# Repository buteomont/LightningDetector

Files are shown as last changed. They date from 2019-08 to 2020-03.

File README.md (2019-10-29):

# LightningDetector  
## An electronic optical lightning detector and strike logger

This device optically detects nearby lightning strikes, records them, and (optionally) energizes a relay for a specified period after each strike.  This version is based on the ESP8266 WEMOS board, but can be adapted to other processors as well.  Firmware development was done in the Arduino IDE.

### Hardware
The hardware is dead simple, as most of the heavy lifting is done by the ESP board and its libraries. An inexpensive solar cell is used as an optical sensor. This solar cell and the WEMOS board is really all that is needed to make a functioning lightning logger.  The output from the solar cell is fed to the processor's ADC (analog-to-digital converter) directly. An optional control circuit (not shown) can be added to energize a relay for a predetermined amount of time whenever lightning is detected.  The circuit can be battery powered, with the strike detector doing double-duty to charge the battery (but don't expect the battery to stay charged unless you are using a _huge_ solar cell).  Thanks to the small size of the WEMOS circuit board, the entire detector will fit inside the head of one of those solar path lights that can be purchased from Dollar Tree, with the solar cell already mounted!  I have included a 3D printer STL file that makes a mount to hold the Wemos board and sounder inside one of these lights. 

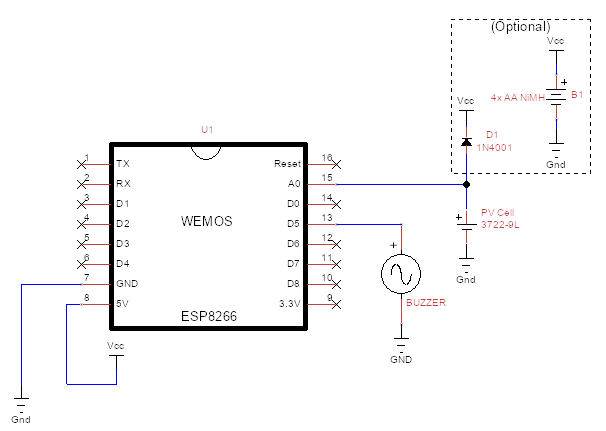
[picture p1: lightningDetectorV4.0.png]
Circuit Schematic Schematic


### Firmware
The program to drive the lightning detector allows you to view or download the strike log and adjust the operating parameters. It operates as a basic web server, while concurrently watching for any lightning in the area.  When a lightning strike is detected, it will record the time and the intensity in the strike log.   

When powered up for the first time, the 8266 will go into "AP mode", since it doesn't know about any wifi routers in the area.  In AP mode, the ESP8266 *is* the router, with an SSID of "**_lightning!_**".  You will need to connect to that "router" and browse to _http://lightning.local_ to configure it.  Enter your household wifi SSID and password and press the _Update_ button.  You can also change the mDNS domain name and sensitivity setting.   

If you enter the SSID or password incorrectly, the lightning detector will never connect to your LAN, and also will not enter AP mode so you can change it!  The way around this is to press the _reset_ button on the WEMOS board and watch for the LED to illuminate.  When it does, press the _reset_ button again.  This will wipe the configuration and cause it to enter AP mode again.  

To reduce false detections, the program will ensure that the length of the strike is above a certain amplitude and within a specific duration window, no shorter and no longer. That window is from 1 to 200 milliseconds and may need to change if too many false positives are recorded or strikes are missed.  The amplitude threshold (sensitivity) of the detector is adjustable on the _/config_ page of the detector's web server.  I've found it's easy to find the right value by putting the detector into place and setting the sensitivity to 1 (maximum sensitivity), and letting it run for a while.  Then noting the values in the strike log makes it easy to adjust the sensitivity to just above the highest value.   

The optional sounder (buzzer) can be enabled or disabled.  The pitch of the beep it produces can be adjusted within a limited range, but be aware that most sounders have a narrow frequency band where they are resonant, so adjusting the pitch will likely affect the volume as well. 

There is no security implemented at this time, so anyone with access to the _/configure_ page can make changes. This will be problematic if you decide to make the logger world-accessible. I purposely did not include a link to the _/configure_ page from the main status page for this reason.  I have plans to add tighter security for this.

The firmware is fully OTA updatable. I would like to see any changes or improvements you come up with!

### Interface
There are several web endpoints that can be accessed when the detector is running and connected to the LAN:
* / or /index.html - The main status page
* /configure - The configuration page for WiFi, LAN, sensitivity, and other changes
* /text - The status and log information in plain text form
* /json - The status and log information in standard machine-readable JSON form

### Problems
* Every WEMOS board I have seen has a stability problem with the ADC while using the WiFi radio.  Turning off the radio seems to give a much more stable reading from the solar cell, but this is not feasible because it must read the solar cell value continuously looking for a strike and it takes several seconds to reconnect the WiFi after being turned back on.  This is a known problem and I have yet to find a solution outside of using an external ADC.
* The detector logs false lightning strikes sometimes right at dawn and right at dusk.  I am not sure what is causing this but I suspect it is related to the stability issue above.  I can prevent a lot of them by reducing the sensitivity but that is not an optimal solution. 

### Planned Enhancements
In addition to fixing the above problems, some of the things I'd like to add when I get the time are
* Security features to require a userid and password when modifying the settings
* The ability to push the strike event to an external service (such as MQTT), email, or SMS account
* More flexibility in configuring the internal parameters
* The ability to remove individual unwanted or error events from the strike log
* Automatically remove strike events from the log that are older than 30 days
* Store the strike log in EEPROM to make it non-volatile

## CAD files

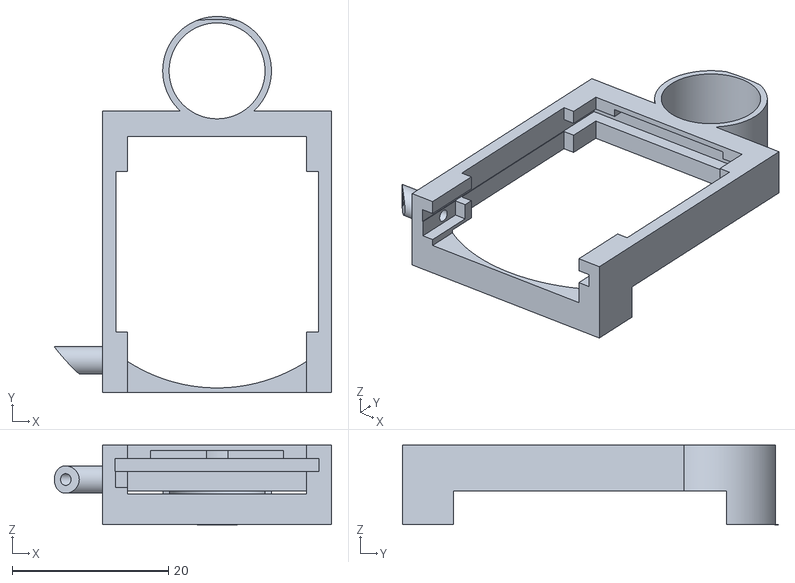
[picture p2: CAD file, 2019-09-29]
case/wemos-holder.stl
35.5 x 48.1 x 10.2

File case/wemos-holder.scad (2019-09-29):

shrinkPCT=3; //%, 1 PLA, 2 PETG, 3 ABS
fudge=.02;  //mm
shrinkFactor=1+shrinkPCT/100;
nozzleDiameter=.4;

$fn=200;

railDepth=1.5; //this is the depth of the slots that the board slides into
metalCapHeight=3.1; //the thickness of the metal cap plus the 8266 board on which it sits

boardWidth=25.9;    //width of the Wemos board
boardLength=34.3;   //length of the Wemos board
boardThickness=1.7; //thickness of the board itself, with a little extra for the groove
boardWallThickness=boardThickness; //the wall thickness at the back of the board groove
boardConnectorEndThickness=4.3;   //the thickness of the board plus the USB connector
antennaWidth=17;    //long dimension of the little PC antenna board
antennaDepth=7;     //short dimension of antenna board
antennaThickness=1; //thickness of antenna board
switchLength=6.5;   //Length of the reset switch, including the gap to the board edge
switchDepth=4.5;    //short dimension of the reset switch
switchHeight=2;     //thickness of the reset switch body
switchButtonOffset=4; //button center from front edge of card
switchButtonDiameter=1.5; //diameter of the reset button access hole
sounderDiameter=11.9;   //diameter of the sounder module
sounderHeight=8.52;    //height of the sounder module
sounderWallThickness=1; //thickness of the wall that holds the sounder in place

baseOuterDiameter=52.2; //the largest diameter of the path light base
baseThickness=1.3;      //the thickness of the plastic base plastic
baseInnerDiameter=40.8; //the diameter of the round embossment in the center of the path light base
baseInnerHeight=4.2;    //the height of the embossment above the base
baseOuterRadius=baseOuterDiameter/2; //sometimes need the radius instead of the diameter

//define a cube that will encompass the entire board. We will remove material from this cube to make the holder
boardCubeHeight=baseInnerHeight+boardConnectorEndThickness+boardThickness;
boardCubeWidth=boardWidth+boardWallThickness*2;
boardCubeLength=boardLength+boardWallThickness; //only need the extra length on the back side, front side flush

//this design works best if it is as close to the edge of the path light wall as possible.  This offset
//is how far the board cube can be moved without going over the edge of the base
boardCubeOffset=(baseOuterRadius+boardCubeLength/2)-(baseOuterRadius+sqrt(pow(baseOuterRadius,2)-pow(boardCubeWidth/2,2))); //this puts the corners of the board right at the edge of the base

boardSpaceWidth=boardWidth-railDepth*2; //the width of the remover for the board and its components 
boardSpaceLength=boardLength-railDepth; //the length of the remover for the board and its components
boardSpaceHeight=boardConnectorEndThickness+metalCapHeight; //this is how tall the remover for the wire space needs to be
boardWireSpaceWidth=boardWidth; //this is the width for the remover for the wire space
boardWireSpaceLength=20.5;      //likewise, the length of the remover
boardWireSpaceOffset=6; //from antenna end of the board


module mount()
  {
  difference()
    {
    union()
      {
      //the main cube that holds the board. Almost everything else is removed from this cube
      translate([0,boardCubeOffset,boardCubeHeight/2+baseThickness])
        {
        cube([boardCubeWidth,boardCubeLength,boardCubeHeight],center=true);
        }
        
      //Add the guide for the reset switch
      translate([-(boardWidth/2+9),
                  boardCubeOffset-(boardLength/2-switchLength/2),
                  baseThickness+baseInnerHeight+boardConnectorEndThickness-boardThickness-switchHeight/2])
        {
        rotate([0,90,0])
          cylinder(h=9,d=switchButtonDiameter+2); //hole housing for the reset button
        }
      
      //add the sounder holder
      translate([0,boardCubeOffset+boardLength/2+sounderDiameter/2+fudge,baseThickness+boardCubeHeight/2])
        {
        cylinder(h=boardCubeHeight,d=sounderDiameter+sounderWallThickness*2,center=true); //hole housing for the sounder
        }
      }
    union() //all of this is removed from the main cube
      {
      cylinder(d=baseOuterDiameter,h=baseThickness+fudge*2); //the thin base
      translate([0,0,baseThickness+fudge])
        {
        cylinder(d=baseInnerDiameter*shrinkFactor, h=baseInnerHeight*shrinkFactor); //the thicker center part of the base
        }
      translate([0,boardCubeOffset-boardWallThickness/2,baseThickness+baseInnerHeight+boardConnectorEndThickness-boardThickness/2])
        {
        cube([boardWidth+.2,boardLength+.2,boardThickness],center=true); //the slot for the card edges
        }
      translate([0,boardCubeOffset-boardWallThickness,baseThickness+baseInnerHeight+boardConnectorEndThickness-boardThickness/2])
        {
        cube([boardSpaceWidth,boardSpaceLength,boardSpaceHeight],center=true); //space for the board components
        }
      translate([0,boardCubeOffset,baseThickness+baseInnerHeight+boardConnectorEndThickness-boardThickness/2])
        {
        cube([boardWireSpaceWidth,boardWireSpaceLength,boardSpaceHeight],center=true); //space for the wire connections. This really should be changed to allow the board to be inserted with the wires attached
        }
      translate([0,boardCubeOffset-antennaDepth/2+boardLength/2,baseThickness+baseInnerHeight+boardConnectorEndThickness+antennaThickness/2-fudge])
        {
        cube([antennaWidth,antennaDepth,antennaThickness],center=true); //space for the antenna board
        }
      translate([-(boardWidth/2-switchDepth/2),boardCubeOffset-(boardLength/2-switchLength/2+boardWallThickness/2),baseThickness+baseInnerHeight+boardConnectorEndThickness-boardThickness-switchHeight/2])
        {
        cube([switchDepth+fudge,switchLength+fudge,switchHeight+fudge],center=true); //space for the reset button
        }
      translate([-(boardWidth/2+8),boardCubeOffset-(boardLength/2-switchLength/2),baseThickness+baseInnerHeight+boardConnectorEndThickness-boardThickness-switchHeight/2])
        {
        rotate([0,90,0])
          cylinder(h=8,d=switchButtonDiameter); //hole for the reset button
        }
      translate([-boardCubeWidth/2-fudge,boardCubeLength/2+boardCubeOffset-2.5,baseThickness+fudge])
        {
        cube([boardCubeWidth+fudge*2,5,baseInnerHeight]); //remover for extraneous bits left over
        }
      //add the sounder
      translate([0,boardCubeOffset+boardLength/2+sounderDiameter/2+fudge,baseThickness+boardCubeHeight/2])
        {
        cylinder(h=boardCubeHeight+fudge,d=sounderDiameter*shrinkFactor,center=true); //hole for the sounder
        }

      }
    fit();
    }
    

  }

//Create a remover ring around the whole thing to make it all fit inside the cap. This is mostly for trimming the reset button guide tube and the sounder holder
module fit()
  {
  difference()
    {
    translate([0,0,baseThickness*shrinkFactor-fudge])
      {
      cylinder(d=baseOuterDiameter+10, h=boardCubeHeight+fudge*2); 
      }
    translate([0,0,baseThickness-fudge])
      {
      cylinder(d=baseOuterDiameter, h=boardCubeHeight+fudge*2); 
      }
    }
  }
  

mount();

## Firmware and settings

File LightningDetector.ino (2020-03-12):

/*
 * LightningDetector.c
 *
 *  Created on: May 9, 2014
 *  Updated on: July 20, 2019
 *      Author: David E. Powell
 *
 *  --------Hardware and Software Enhancements----------
 *  - Move strike log to EEPROM
 *
 */

#include <ArduinoMqttClient.h>
#include <ArduinoOTA.h>
#include <ESP8266WiFi.h>
#include <ESP8266WebServer.h>
#include <ESP8266mDNS.h>
#include "Arduino.h"
#include <pgmspace.h>
#include <ctype.h>
#include <ESP_EEPROM.h>
#include <stdio.h>
#include <Esp.h>
#include <TimeLib.h>
#include "LightningDetector.h"
#include "configpage.h"

#ifndef AP_SSID
  #define AP_SSID "lightning!"
  #define AP_PASS ""
  #define MY_MDNS "lightning" 
  #endif

const char *htmlCr="<br>";
const char *textCr="\n\r";

int lastReading = 0;
int thisReading = 0;
int errval=128; //half way
int resetCounter=0; //keeps the LED lit long enough to see it when a strike happens
int resetDelay=100;  //this is how many milliseconds (approx) the LED stays lit after lightning is seen
unsigned long strikes[MAX_STRIKES];       //strike time log
unsigned int strikeIntensity[MAX_STRIKES];//strike brightness log
int strikeCount=0;  //number of strikes in the log
boolean done=false;
int strikeStage=0;   //to keep track of which part of the strike we are working
long strikeWaitTime; //to keep from having to use delay()
int intensity;       //temporary storage to record the intensity of the strike for the log
boolean configured=false;  //don't look for lightning until we are set up
time_t tod=0;         //time of day
unsigned long ledTime=millis(); //target time to turn off the LED
unsigned long mqttWait=millis(); //used to slow down MQTT connect retries
unsigned long looptime=0;

//IPAddress timeServer(132,163,96,2);  //time.nist.gov
IPAddress timeServer;

ESP8266WebServer server(80);
WiFiUDP Udp; //for getting time from NIST
unsigned int localPort = 8888;  // local port to listen for UDP packets for time query

typedef struct 
  {
  boolean valid=false; //***** This must remain the first item in this structure! *******
  char ssid[SSID_SIZE] = AP_SSID;
  char password[PASSWORD_SIZE] = AP_PASS;
  int statIP[4]={0,0,0,0};
  int statGW[4]={0,0,0,0};
  char myMDNS[MDNS_SIZE]=MY_MDNS;
  int tzOffset=-5;
  int sensitivity=10;  //successive readings have to be at least this much larger than the last reading to register as a strike
  boolean useStatic=false;
  boolean beepOnStrike=true;
  int beepPitch=SOUNDER_PITCH;
  boolean useMqtt=false;
  char mqttBrokerAddress[ADDRESS_SIZE]=AIO_SERVER;
  int mqttBrokerPort=AIO_SERVERPORT;
  char mqttUsername[USERNAME_SIZE]=AIO_USERNAME;
  char mqttPassword[PASSWORD_SIZE]=AIO_KEY;
  char mqttTopic[MQTT_TOPIC_SIZE]=MQTT_TOPIC;
  int dnsServer[4]={0,0,0,0};
  } conf;

conf settings; //all settings in one struct makes it easier to store in EEPROM

// Set up the MQTT client class by passing in the WiFi client and MQTT server and login details.
WiFiClient client;
MqttClient mqttClient(client);

void setup()
  {
  //Set up the serial communications
  Serial.begin(115200); 
  Serial.setTimeout(10000);
  Serial.println();
  delay(500);
  Serial.println("Starting up...");

  //initialze the outputs
  pinMode(LIGHTNING_LED_PIN, OUTPUT);  //we'll use the led to indicate detection
  digitalWrite(LIGHTNING_LED_PIN,HIGH); //High is off on the dorkboard
  pinMode(BLUE_LED_PIN, OUTPUT);  //we'll use this led to indicate when we're looking for server connections
  digitalWrite(BLUE_LED_PIN,HIGH); //
  pinMode(RELAY_PIN, OUTPUT);  //set up the relay
  digitalWrite(RELAY_PIN,LOW); //off

  EEPROM.begin(sizeof(settings)); //fire up the eeprom section of flash
  Serial.print("Settings object size=");
  Serial.println(sizeof(settings));

  //look for a double-click on the reset button.  If reset is clicked, then clicked
  //again while the LED is on, then do a factory reset. We detect this by reading the
  //"configured" value from EEPROM and setting it to false, turning on the LED, then 
  //turning the LED off and writing the value back to EEPROM two seconds later.
  boolean conf;
  boolean noConf=false;
  EEPROM.get(0,conf);                 //save original value
  EEPROM.put(0,noConf);               //write "false" for non-configured
  EEPROM.commit();                    //do the write
  digitalWrite(LIGHTNING_LED_PIN,LOW);//Turn on the LED
  delay(2000);                        //wait a sec
  digitalWrite(LIGHTNING_LED_PIN,HIGH);//Turn the LED back off
  EEPROM.put(0,conf);                 //If we are here then no double-click, write the original back
  EEPROM.commit();                    //do the write

  loadSettings(); //load the editable settings from eeprom





//temporary///////////
settings.useMqtt=true;
sprintf(settings.mqttBrokerAddress,"%s",AIO_SERVER);
settings.mqttBrokerPort=AIO_SERVERPORT;
sprintf(settings.mqttUsername,"%s",AIO_USERNAME);
sprintf(settings.mqttPassword,"%s",AIO_KEY);
sprintf(settings.mqttTopic,"%s",MQTT_TOPIC); 
settings.dnsServer[0]=DNS_SERVER0;
settings.dnsServer[1]=DNS_SERVER1;
settings.dnsServer[2]=DNS_SERVER2;
settings.dnsServer[3]=DNS_SERVER3;
EEPROM.put(0,settings);
//////////////////////



  //initialize variables
  
  resetCounter=0;
  thisReading=analogRead(PHOTO_PIN);
  lastReading=thisReading;
  
  //Get the WiFi going
  if (!settings.valid) //Are we already configured?  If not then use AP mode
    {
    Serial.print("Configuring soft access point. SSID is \""+String(settings.ssid)+"\". ");
    WiFi.softAP(AP_SSID);
  
    IPAddress myIP = WiFi.softAPIP();
    Serial.print("IP address is ");
    Serial.println(myIP);
    }
  else
    {
    configured=true;  //we are configured
    
    Serial.println("\n***** Settings ******");
    Serial.print("valid=");Serial.println(settings.valid?"true":"false");
    Serial.print("ssid="); Serial.println(settings.ssid);
    Serial.print("password="); Serial.println(settings.password);
    Serial.print("statIP="); Serial.print(settings.statIP[0]);Serial.print(".");Serial.print(settings.statIP[1]);Serial.print(".");Serial.print(settings.statIP[2]);Serial.print(".");Serial.println(settings.statIP[3]);
    Serial.print("statGW="); Serial.print(settings.statGW[0]);Serial.print(".");Serial.print(settings.statGW[1]);Serial.print(".");Serial.print(settings.statGW[2]);Serial.print(".");Serial.println(settings.statGW[3]);
    Serial.print("myMDNS="); Serial.println(settings.myMDNS);
    Serial.print("tzOffset="); Serial.println(settings.tzOffset);
    Serial.print("sensitivity="); Serial.println(settings.sensitivity);
    Serial.print("useStatic="); Serial.println(settings.useStatic?"true":"false");
    Serial.print("beepOnStrike="); Serial.println(settings.beepOnStrike?"true":"false");
    Serial.print("beepPitch="); Serial.println(settings.beepPitch);
    Serial.print("useMqtt="); Serial.println(settings.useMqtt?"true":"false");
    Serial.print("mqttBrokerAddress="); Serial.println(settings.mqttBrokerAddress);
    Serial.print("mqttBrokerPort="); Serial.println(settings.mqttBrokerPort);
    Serial.print("mqttUsername="); Serial.println(settings.mqttUsername);
    Serial.print("mqttPassword="); Serial.println(settings.mqttPassword);
    Serial.print("mqttTopic="); Serial.println(settings.mqttTopic);
    Serial.print("dnsServer="); Serial.print(settings.dnsServer[0]);Serial.print(".");Serial.print(settings.dnsServer[1]);Serial.print(".");Serial.print(settings.dnsServer[2]);Serial.print(".");Serial.println(settings.dnsServer[3]);
    Serial.println("***** Settings ******\n");


    WiFi.disconnect();
    WiFi.hostname(settings.myMDNS);
    if (settings.useStatic)
      {
      String adr=String(settings.statIP[0])+"."+settings.statIP[1]+"."+settings.statIP[2]+"."+settings.statIP[3];
      Serial.println("Using static addressing: "+adr);
      IPAddress staticIP(settings.statIP[0],settings.statIP[1],settings.statIP[2],settings.statIP[3]); //ESP static ip
      IPAddress gateway(settings.statGW[0],settings.statGW[1],settings.statGW[2],settings.statGW[3]);   //IP Address of your WiFi Router (Gateway)
      IPAddress subnet(255, 255, 255, 0);  //Subnet mask
      IPAddress dns(settings.dnsServer[0],settings.dnsServer[1],settings.dnsServer[2],settings.dnsServer[3]);   //IP Address of the DNS server
      WiFi.config(staticIP, gateway, subnet, dns);
      }
      
    WiFi.mode(WIFI_STA);
    Serial.println("Connecting to "+String(settings.ssid)+" with password "+String(settings.password));
    WiFi.begin(settings.ssid, settings.password);
    Serial.print("Connecting");
  
    // Wait for connection
    int waitCount=150;
    while (WiFi.status() != WL_CONNECTED) 
      {
      delay(500);
      Serial.print(".");
      if (--waitCount<=0)
        {
        Serial.println("\n\nTimeout waiting to connect, resetting.");
        ESP.restart();
        }
      }
        
    Serial.println("");
    Serial.print("Connected to ");
    Serial.println(settings.ssid);
    Serial.print("IP address: ");
    Serial.println(WiFi.localIP());       
    }

  if (MDNS.begin(settings.myMDNS)) {
    Serial.print("MDNS responder started as ");
    Serial.print(settings.myMDNS);
    Serial.println(".local");
  }

  Serial.println("\n...Configuring OTA updater");
  ArduinoOTA.onStart([]() 
    {
    String type;
    if (ArduinoOTA.getCommand() == U_FLASH) 
      {
      type = "sketch";
      }
    else 
      { // U_SPIFFS
      type = "filesystem";
      }

    // NOTE: if updating SPIFFS this would be the place to unmount SPIFFS using SPIFFS.end()
    Serial.println("Start updating " + type);
    });
  ArduinoOTA.onEnd([]() {Serial.println("\nEnd");});
  ArduinoOTA.onProgress([](unsigned int progress, unsigned int total) 
    {
    Serial.printf("Progress: %u%%\r", (progress / (total / 100)));
    });
  ArduinoOTA.onError([](ota_error_t error) 
    {
    Serial.printf("Error[%u]: ", error);
    if (error == OTA_AUTH_ERROR) 
      {
      Serial.println("Auth Failed");
      }
    else if (error == OTA_BEGIN_ERROR) 
      {
      Serial.println("Begin Failed");
      }
    else if (error == OTA_CONNECT_ERROR) 
      {
      Serial.println("Connect Failed");
      }
    else if (error == OTA_RECEIVE_ERROR) 
      {
      Serial.println("Receive Failed");
      }
    else if (error == OTA_END_ERROR) 
      {
      Serial.println("End Failed");
      }
    });
  ArduinoOTA.begin();

    // Set up the MQTT client class by passing in the WiFi client and MQTT server and login details.
    if (settings.useMqtt)
      {
      Serial.println("Attempting to connect to MQTT broker...");
//      mqttClient.setUsernamePassword(settings.mqttUsername, settings.mqttPassword);
      if (!mqttClient.connect(settings.mqttBrokerAddress, settings.mqttBrokerPort)) 
        {
        Serial.print("MQTT connection failed! Error code = ");
        Serial.println(mqttClient.connectError());
        }
      else
        {
        Serial.println("MQTT connected!");
        }
      }

  Serial.println("\n...Configuring HTTP server");
  server.on("/", documentRoot);
  server.on("/index.html", documentRoot);
  server.on("/json", sendJson);
  server.on("/text", sendText);
  server.on("/configure", setConfig);
  server.on("/clear", clearLog);
  server.on("/bad", []() 
    {
    Serial.println("Received request for bad data");
    server.send(200, "text/plain", "This is a bad URL. Don't ever do that again.");
    Serial.println("Response sent for bad data");
    });
  server.onNotFound(pageNotFound);
  server.begin();
  Serial.println("HTTP server started");
  strikeWaitTime=millis(); //initialize the delay counter

  if (configured)
    {
    Udp.begin(localPort);
    tod=getNtpTime(); //initialize the TOD clock
    setTime(tod);
    }
    
  Serial.print("millis() is ");
  Serial.println(millis());
  Serial.print("now() is ");
  Serial.println(now());
  
//  Serial.print("The time is ");
//  if (tod>0)
//    {
//    char timebuf[25];
//    Serial.println(displayTime(tod,timebuf," "));
//    }
//  else
//    Serial.println("unknown.");

//  Serial.print("setup() running on core ");
//  Serial.println(xPortGetCoreID());

  //Ready to loop
  Serial.println("\n*** Configuration ***");
  Serial.println(getConfiguration(TYPE_TEXT));
  Serial.println("\n*** Status ***");
  Serial.println(getStatus(TYPE_TEXT));
  Serial.println("\n*** Events ***");
  Serial.println(getStrikes(TYPE_TEXT));

  Serial.println("Ready.");
  Serial.println("");
  }

void loop()
  {
  long lt=millis()-looptime;
  if (lt>3)
    Serial.println("---loop time: "+String(lt)+"milliseconds.");
  looptime=millis();
  server.handleClient();
  MDNS.update();
  ArduinoOTA.handle();

  if (settings.useMqtt)
    {
    if (!mqttClient.connected())
      {
      Serial.println("Attempting to connect to MQTT broker...");
      if (!mqttClient.connect(settings.mqttBrokerAddress, settings.mqttBrokerPort)) 
        {
        Serial.print("MQTT connection failed! Error code = ");
        Serial.println(mqttClient.connectError());
        }
      else
        {
        Serial.println("MQTT connected!");
        }
      }
    else
      {
      mqttClient.poll(); //keep the fire burning
      }
    }
    
  //If setting the clock failed in setup, try again
  if (tod==0 && configured)
    {
    tod=getNtpTime(); //initialize the TOD clock
    if (tod>0)
      setTime(tod);
    }
    
  manageLED(LED_CHECK,0); //turn off the LED if it's time
  
  //Don't read the sensor too fast or else it will disconnect the wifi
  if(!configured || millis()%10 != 0)
    return;
    
  checkForStrike();
  }

//format the time to be human-readable
char* displayTime(time_t mytime, char* buf, String separator)
  {
  // digital clock display of the time
  String tmplate="%d/%d/%d"+separator+"%d:%02d:%02d";
  sprintf(buf,tmplate.c_str(), month(mytime),
                        day(mytime),
                        year(mytime),
                        hour(mytime),
                        minute(mytime),
                        second(mytime)); 
  return buf;
  }



/*-------- NTP code ----------*/

byte packetBuffer[NTP_PACKET_SIZE]; // NTP time is in the first 48 bytes of message

time_t getNtpTime()
  {
  while (Udp.parsePacket() > 0) ; // discard any previously received packets
  
  int hostFound=WiFi.hostByName(NIST_HOST, timeServer);
  if (hostFound!=1)
    {
    Serial.print("Error resolving address of time server ");
    Serial.print(NIST_HOST);
    Serial.print(":");
    Serial.println(hostFound);
    return 0;
    }
  Serial.print("NTP server is at ");
  Serial.println(timeServer);
    
  Serial.print("Transmit NTP Request to ");
  Serial.println(timeServer);
  sendNTPpacket(timeServer);
  uint32_t beginWait = millis();
  while (millis() - beginWait < 16000) 
    {
    int size = Udp.parsePacket();
    if (size >= NTP_PACKET_SIZE) 
      {
      Serial.println("Received NTP Response");
      Udp.read(packetBuffer, NTP_PACKET_SIZE);  // read packet into the buffer
      
      unsigned long secsSince1900;
      // convert four bytes starting at location 40 to a long integer
      secsSince1900 =  (unsigned long)packetBuffer[40] << 24;
      secsSince1900 |= (unsigned long)packetBuffer[41] << 16;
      secsSince1900 |= (unsigned long)packetBuffer[42] << 8;
      secsSince1900 |= (unsigned long)packetBuffer[43];
      return secsSince1900 - 2208988800UL + settings.tzOffset * SECS_PER_HOUR;
      }
    if ((millis()-beginWait) % 3000==0) //re-request the time every 3 seconds until we get it
      {
      delay(1); //don't loop more than once per millisecond
      Serial.println("Resending NTP Request");
      sendNTPpacket(timeServer);
      }
    }
  Serial.println("No NTP Response :-(");
  return 0; // return 0 if unable to get the time
  }

// send an NTP request to the time server at the given address
void sendNTPpacket(IPAddress &address)
  {
  // set all bytes in the buffer to 0
  memset(packetBuffer, 0, NTP_PACKET_SIZE);
  // Initialize values needed to form NTP request
  // (see URL above for details on the packets)
  packetBuffer[0] = 0b11100011;   // LI, Version, Mode
  packetBuffer[1] = 0;     // Stratum, or type of clock
  packetBuffer[2] = 6;     // Polling Interval
  packetBuffer[3] = 0xEC;  // Peer Clock Precision
  // 8 bytes of zero for Root Delay & Root Dispersion
  packetBuffer[12]  = 49;
  packetBuffer[13]  = 0x4E;
  packetBuffer[14]  = 49;
  packetBuffer[15]  = 52;
  // all NTP fields have been given values, now
  // you can send a packet requesting a timestamp:                 
  Udp.beginPacket(address, 123); //NTP requests are to port 123
  Udp.write(packetBuffer, NTP_PACKET_SIZE);
  Udp.endPacket();
  }


char* getConfigPage(String message)
  {
  char temp[11];
  sprintf_P(configBuf,(PGM_P)FPSTR(configPage),
              message.c_str(),
              VERSION,
              settings.ssid,
              settings.password,
              settings.myMDNS,
              settings.useStatic?" checked":"",
              settings.statIP[0],
              settings.statIP[1],
              settings.statIP[2],
              settings.statIP[3],
              settings.statGW[0],
              settings.statGW[1],
              settings.statGW[2],
              settings.statGW[3],
              settings.tzOffset,
              settings.sensitivity,
              settings.beepOnStrike?" checked":"",
              settings.beepPitch);
  return configBuf;
  }

void clearLog()
  {
  Serial.println("Received clear log request");
  Serial.println("POST data: "+server.arg("plain"));
  char res[]="CLEAR";
  if (server.hasArg("plain")== false
    ||strcmp(res,server.arg("clear_log").c_str())!=0) 
    {
    server.send(400, "text/html", "Request method must be POST with clear_log=true"); //not a POST request
    Serial.println("Not a POST or invalid request, failed.");
    }
  else
    {
    strikeCount=0;  //reset the pointer to the log head
    Serial.println("Log cleared.");
    server.sendHeader("Location", String("/"), true);
    server.send(303, "text/plain", ""); //send them to the main page
    manageLED(LED_ON,CLEAR_LOG_LED_TIME); //turn on the LED for a bit
    if (settings.beepOnStrike)
      tone(SOUNDER_PIN,settings.beepPitch,CLEAR_LOG_LED_TIME);
    }
  }
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

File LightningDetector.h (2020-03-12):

//#include "iomap_mhetesp32minikit.h"

#define VERSION          "5.0.0" // compiled on "__DATE__" at " __TIME__

#define SOUNDER_PIN         D5   //to make the beep
#define SOUNDER_PITCH       2048 //Hz
#define SOUNDER_DURATION    100  //milliseconds
#define CLEAR_LOG_LED_TIME  2000 //milliseconds to show LED when clearing log

#define LIGHTNING_LED_PIN LED_BUILTIN 
#define BLUE_LED_PIN    D4
#define RELAY_PIN       D2      //relay on digital 12

#define PHOTO_PIN       A0      //input from solar cell
#define ERROR_PIN       D1      //analog output for ambient light compensation
#define MAX_READING     1023    //the largest value from the A/D converter
#define MAX_STRIKES     200     //size of strike log
#define HOUR_MILLISECS 3600000L //60*60*1000
#define DAY_MILLISECS 86400000L //24*60*60*1000
#define MIN_STRIKE_WIDTH 1      //Strike must last at least this many milliseconds
#define MAX_STRIKE_WIDTH 400    //But no longer than this
#define HTML_CR         "<br>"
#define TEXT_CR         "\n\r"
#define OFF             HIGH
#define ON              LOW
#define TYPE_TEXT       0
#define TYPE_HTML       1
#define TYPE_TABLE      2
#define TYPE_JSON       3
#define LED_ON          0
#define LED_OFF         1
#define LED_CHECK       2

#define SSID_SIZE 32
#define PASSWORD_SIZE 64
#define MDNS_SIZE 256
#define ADDRESS_SIZE 18
#define USERNAME_SIZE 32

#define NIST_PORT     13
#define NIST_HOST     "pool.ntp.org"
#define NTP_PACKET_SIZE 48
#define DNS_SERVER0  8
#define DNS_SERVER1  8
#define DNS_SERVER2  8
#define DNS_SERVER3  8

#define AIO_SERVER      "192.168.1.118" //"broker.hivemq.com" //"192.168.1.99"
#define AIO_SERVERPORT  1883                   // use 8883 for SSL
#define AIO_USERNAME    "southLightning"
#define AIO_KEY         "sFlash"
#define MQTT_TOPIC      "tinyhouse/lightning/southside/brightness"
#define MQTT_TOPIC_SIZE 64

#define DEBUG false  //to show plotter graph

// Error codes copied from the MQTT library
#define MQTT_CONNECTION_REFUSED            -2
#define MQTT_CONNECTION_TIMEOUT            -1
#define MQTT_SUCCESS                        0
#define MQTT_UNACCEPTABLE_PROTOCOL_VERSION  1
#define MQTT_IDENTIFIER_REJECTED            2
#define MQTT_SERVER_UNAVAILABLE             3
#define MQTT_BAD_USER_NAME_OR_PASSWORD      4
#define MQTT_NOT_AUTHORIZED                 5

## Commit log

2019-07-29 Major modifications. Replaced delays with millis() counter. Removed the compensation circuit. Added HTML, text, and JSON output.
    [LightningDetector.h, LightningDetector.ino]
2019-07-29 Removed the compensation circuit
    [lightningDetectorV4.0.dsn]
2019-08-04 Added factory reset using reset button on board
    [LightningDetector.ino]
2019-08-10 Rearranged some data and fixed the JSON output
    [LightningDetector.ino]
2019-08-12 Added board holder for case, fixed time bug
    [wemos-holder.scad, wemos-holder.stl]
2019-08-14 Reduced the minimum strike time to 1 millisecond
2019-08-14 Reset hole and guide changes
    [wemos-holder.scad, wemos-holder.stl]
2019-08-17 fixed bug that would hang on large strike log
    [LightningDetector.h, LightningDetector.ino]
2019-08-24 Added periodic check in case time doesn't get set during setup. Added tone connected to D5 at 1900Hz
    [LightningDetector.h, LightningDetector.ino]
2019-08-26 New schematic
2019-08-26 Added buzzer holder
    [wemos-holder.scad, wemos-holder.stl]
2019-08-29 fixed connection problem when in AP mode
    [LightningDetector.ino]
2019-09-07 Fixed problem with incorrect strike reporting when over MAX_STRIKES strikes in log
    [LightningDetector.h, LightningDetector.ino]
2019-09-09 Fixed error reporting strike summary Added footnote to config page
    [LightningDetector.ino]
2019-09-15 Added beep pitch adjustment
2019-09-15 Added bit about sounder pitch
2019-09-15 Mentioned STL file
2019-09-24 Turn on LED when clearing log
2019-09-29 Fine-tuned the fit
    [wemos-holder.scad, wemos-holder.stl]
